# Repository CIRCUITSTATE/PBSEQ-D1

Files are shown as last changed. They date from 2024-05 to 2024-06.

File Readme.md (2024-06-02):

# PBSEQ-D1

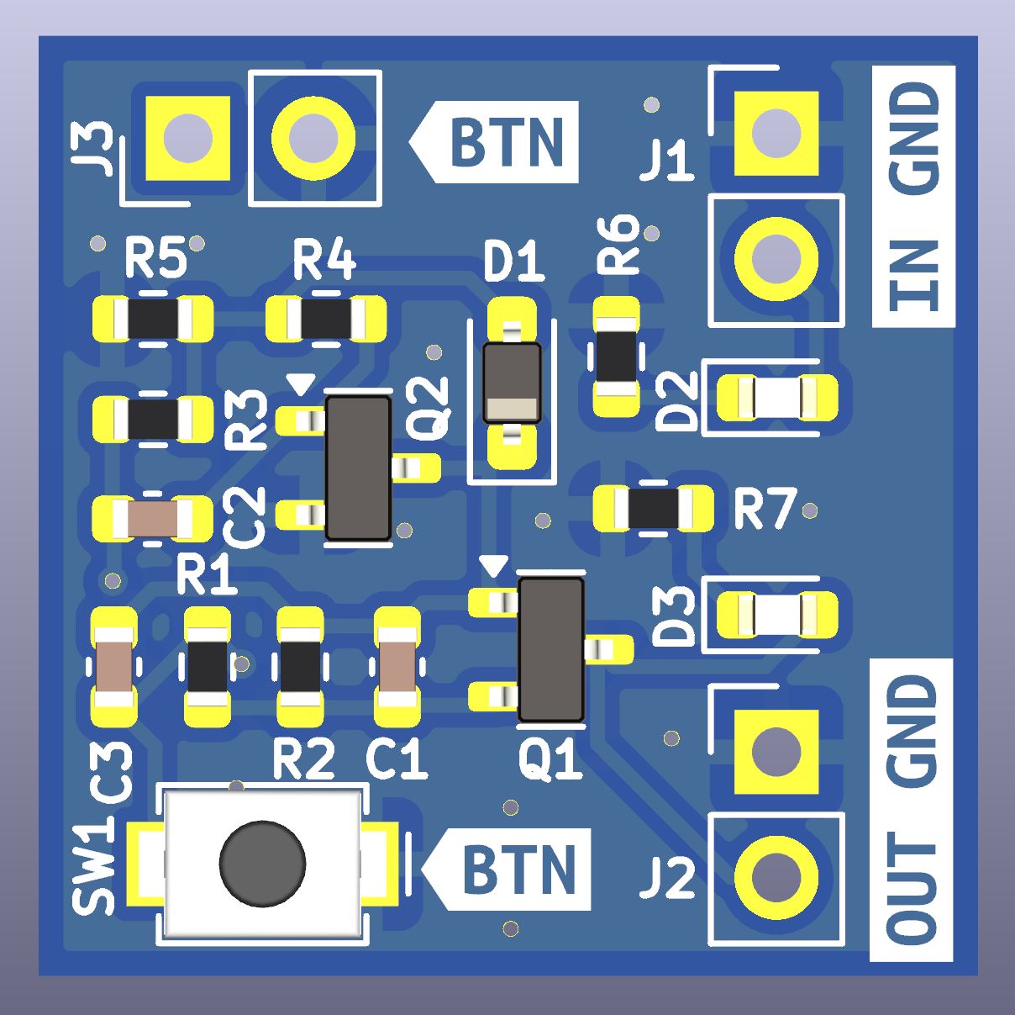
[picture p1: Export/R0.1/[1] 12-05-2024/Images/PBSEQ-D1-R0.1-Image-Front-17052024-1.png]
PBSEQ-D1 Front


**PBSEQ-D1** is a push-button based power sequencer demo board designed in KiCad. You can press the push-button momentarily to turn on the output. Pressing and and holding will turn off the output. A PMOS transistor is used as a high-side switch to control the power. An NMOS transistor controls the power sequencing. This demo project is fully open-source and you can find the source design files here.

A tutorial of designing and testing the circuit will soon be available at [CIRCUITSTATE](https://www.circuitstate.com/).

## Project Details

- **Parent Project:** PBSEQ
- **Variant Name:** PBSEQ-D1
- **Latest Revision:** `R0.2`
- **EDA Tools:** KiCad V8
- **Layer Count:** 2
- **Board Thickness:** 1.6 mm
- **Dimensions:** 19 x 19 mm

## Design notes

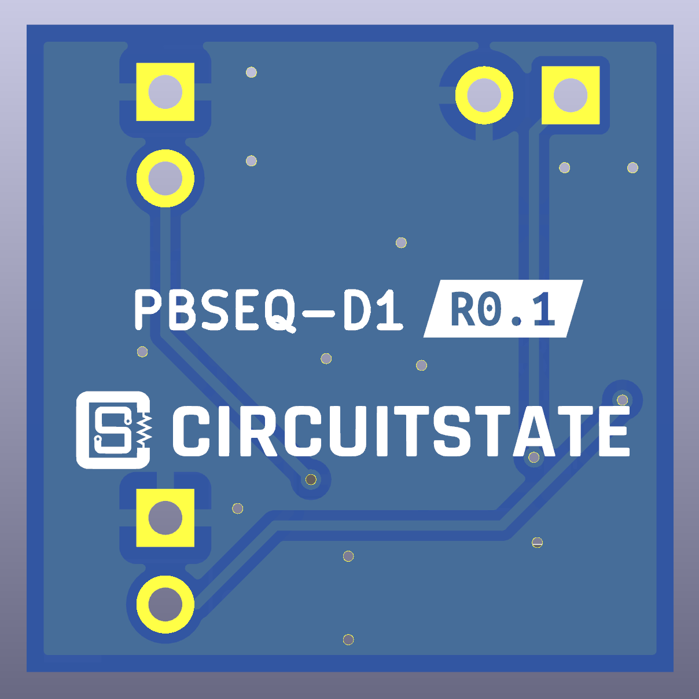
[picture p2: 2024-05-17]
Export/R0.1/[1] 12-05-2024/Images/PBSEQ-D1-R0.1-Image-Back-17052024-1.png

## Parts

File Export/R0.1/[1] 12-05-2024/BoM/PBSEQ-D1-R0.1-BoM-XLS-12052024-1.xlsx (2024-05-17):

# | Reference | Value | Name | Footprint | Qty | MPN | MFR | DNP
1 | C1 | 0.1uF |  | Capacitor_SMD:C_0603_1608Metric | 1 | 0603B104J500CT | Walsin
2 | C2 | 10uF |  | Capacitor_SMD:C_0603_1608Metric | 1 | 0603X106K100CT | Walsin
3 | C3 | 1uF |  | Capacitor_SMD:C_0603_1608Metric | 1 | CC0603KRX5R9BB105 | Yageo
4 | D1 | 1N4148 |  | Diode_SMD:D_SOD-323_HandSoldering | 1 | 1N4148WS | onsemi
5 | D2 | RED | INPUT | LED_SMD:LED_0603_1608Metric | 1 | 19-21SURC/S530-A2/TR8 | Everlight
6 | D3 | YELLOW | OUTPUT | LED_SMD:LED_0603_1608Metric | 1 | 19-213/Y2C-FN2P2VZ/3T | Everlight
7 | J1 | POWER IN | POWER IN | Connector_PinHeader_2.54mm:PinHeader_1x02_P2.54mm_Vertical | 1 | DNP
8 | J2 | POWER OUT | POWER OUT | Connector_PinHeader_2.54mm:PinHeader_1x02_P2.54mm_Vertical | 1 | DNP
9 | J3 | BUTTON | POWER IN | Connector_PinHeader_2.54mm:PinHeader_1x02_P2.54mm_Vertical | 1 | DNP
10 | Q1 | AO3401A |  | Package_TO_SOT_SMD:SOT-23 | 1 | AO3401A | Alpha & Omega
11 | Q2 | AO3400A |  | Package_TO_SOT_SMD:SOT-23 | 1 | AO3400A | Alpha & Omega
12 | R1 | 10K |  | Resistor_SMD:R_0603_1608Metric | 1 | WR06X1002FTL | Walsin
13 | R4 | 300K |  | Resistor_SMD:R_0603_1608Metric | 1 | WR06X3003FTL | Walsin
14 | R5 | 1M |  | Resistor_SMD:R_0603_1608Metric | 1 | WR06X1004FTL | Walsin
15 | R6 | 1K |  | Resistor_SMD:R_0603_1608Metric | 1 | WR06X1001FTL | Walsin
16 | R7 | 200R |  | Resistor_SMD:R_0603_1608Metric | 1 | WR06X2000FTL | Walsin
17 | R2,R3 | 100K |  | Resistor_SMD:R_0603_1608Metric | 2 | WR06X1003FTL | Walsin
18 | SW1 | BUTTON | BUTTON | CIRCUITSTATE_Switch_SMD:CK_SW_SPST_UK-B0273-SP25Y | 1 | TS-1088R-02526 | XUNPU

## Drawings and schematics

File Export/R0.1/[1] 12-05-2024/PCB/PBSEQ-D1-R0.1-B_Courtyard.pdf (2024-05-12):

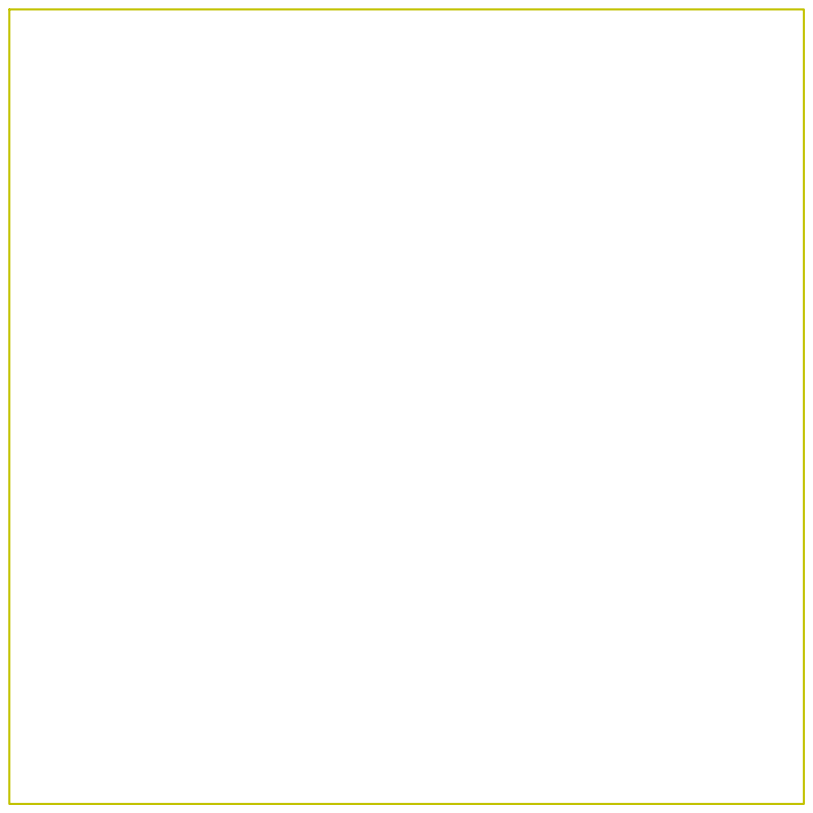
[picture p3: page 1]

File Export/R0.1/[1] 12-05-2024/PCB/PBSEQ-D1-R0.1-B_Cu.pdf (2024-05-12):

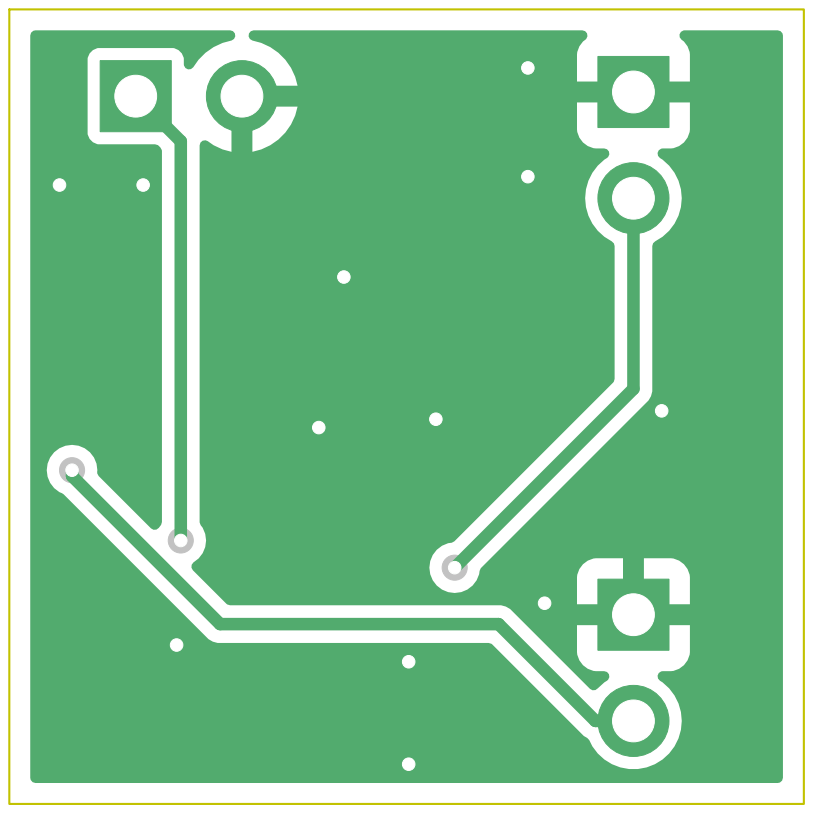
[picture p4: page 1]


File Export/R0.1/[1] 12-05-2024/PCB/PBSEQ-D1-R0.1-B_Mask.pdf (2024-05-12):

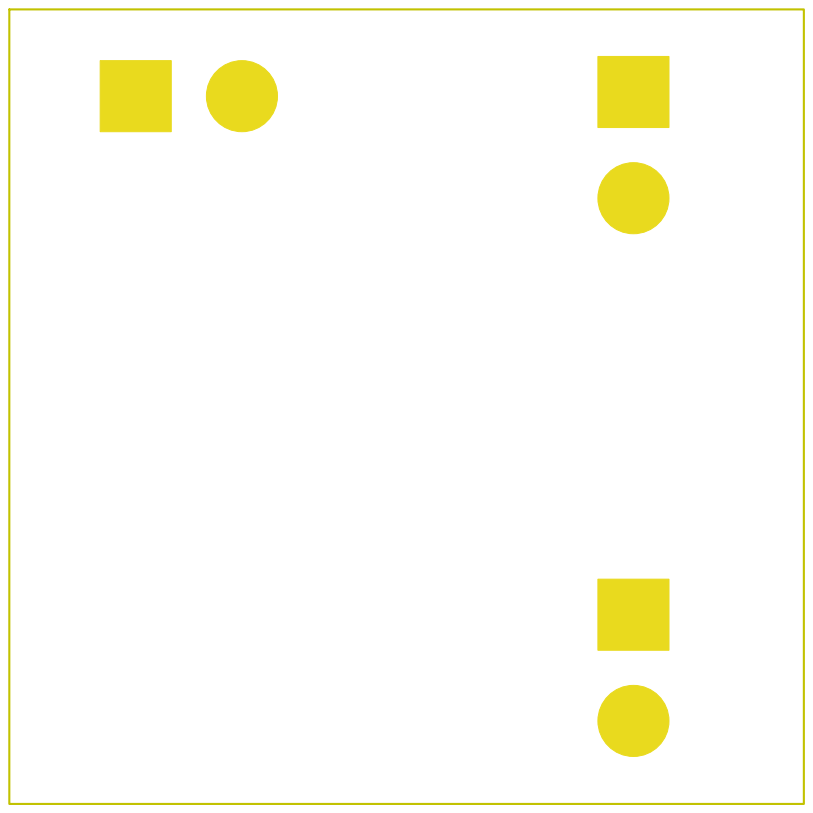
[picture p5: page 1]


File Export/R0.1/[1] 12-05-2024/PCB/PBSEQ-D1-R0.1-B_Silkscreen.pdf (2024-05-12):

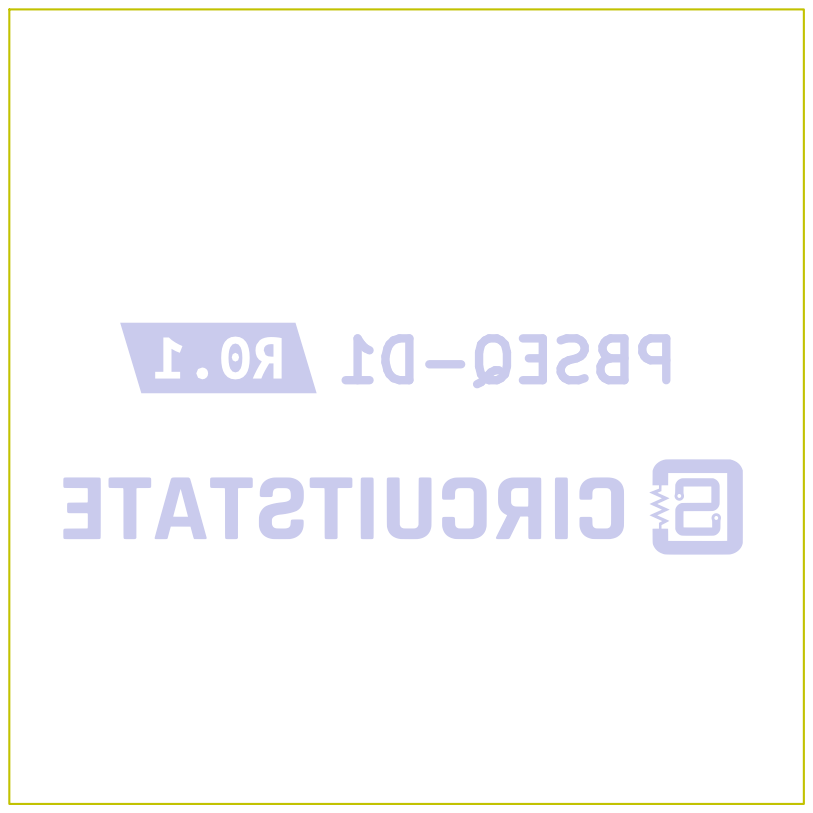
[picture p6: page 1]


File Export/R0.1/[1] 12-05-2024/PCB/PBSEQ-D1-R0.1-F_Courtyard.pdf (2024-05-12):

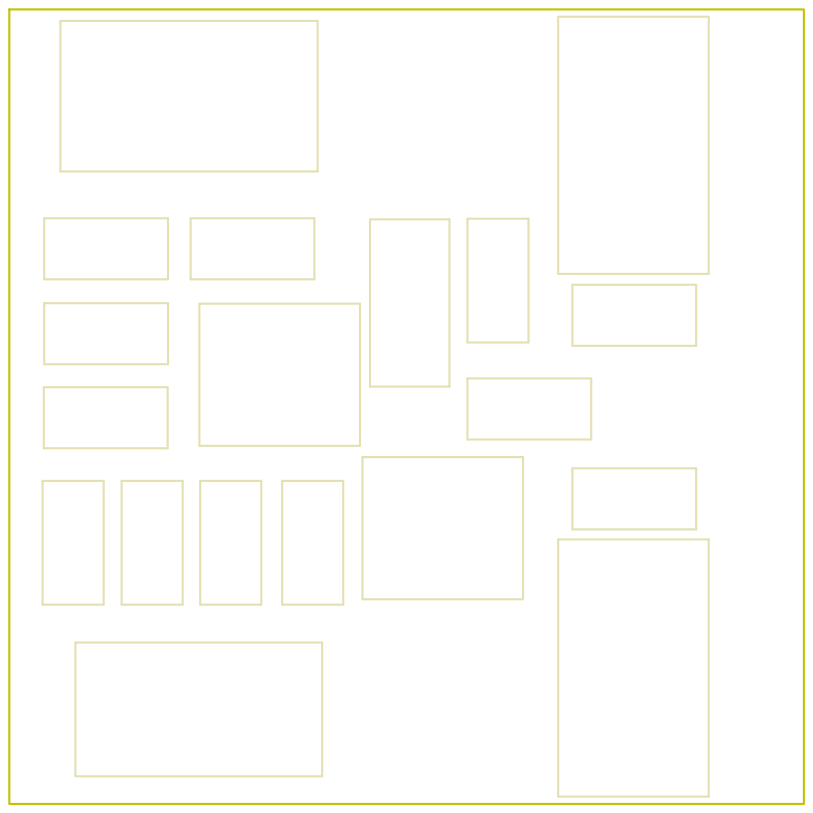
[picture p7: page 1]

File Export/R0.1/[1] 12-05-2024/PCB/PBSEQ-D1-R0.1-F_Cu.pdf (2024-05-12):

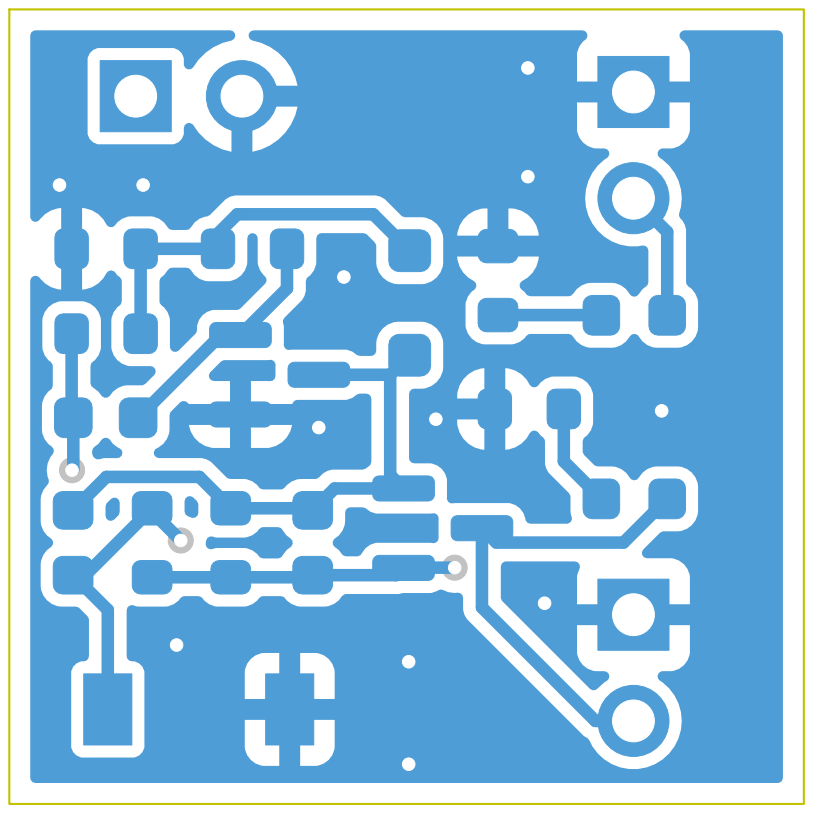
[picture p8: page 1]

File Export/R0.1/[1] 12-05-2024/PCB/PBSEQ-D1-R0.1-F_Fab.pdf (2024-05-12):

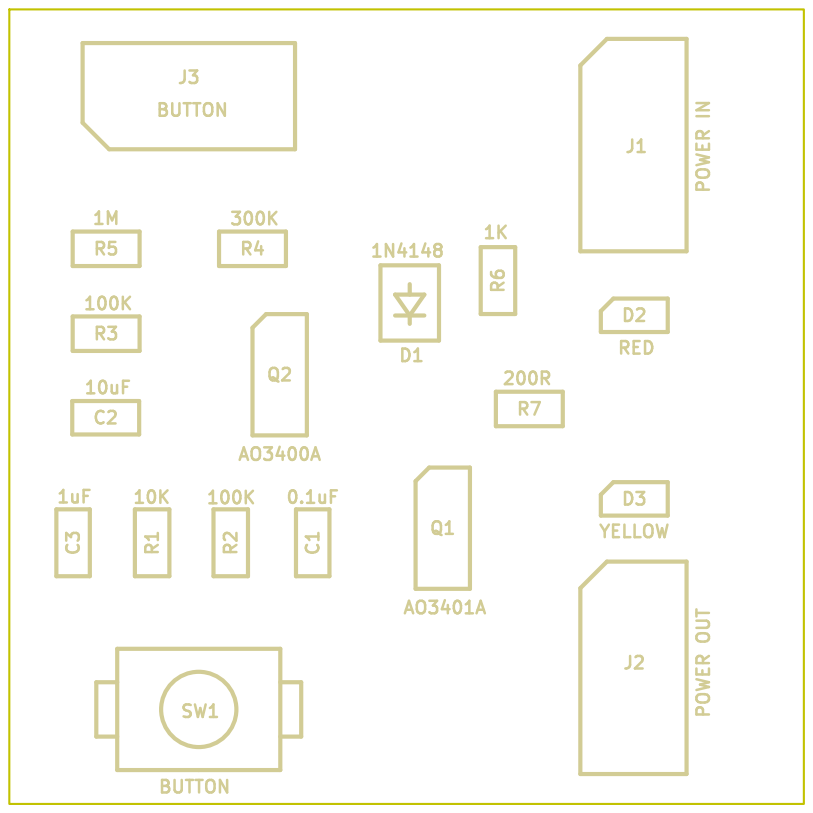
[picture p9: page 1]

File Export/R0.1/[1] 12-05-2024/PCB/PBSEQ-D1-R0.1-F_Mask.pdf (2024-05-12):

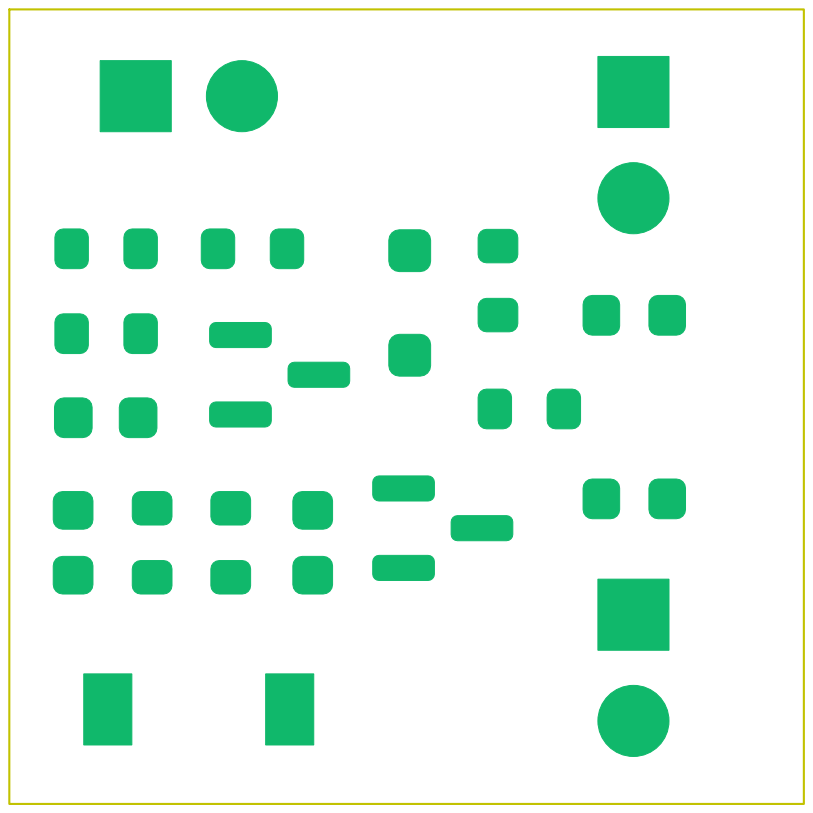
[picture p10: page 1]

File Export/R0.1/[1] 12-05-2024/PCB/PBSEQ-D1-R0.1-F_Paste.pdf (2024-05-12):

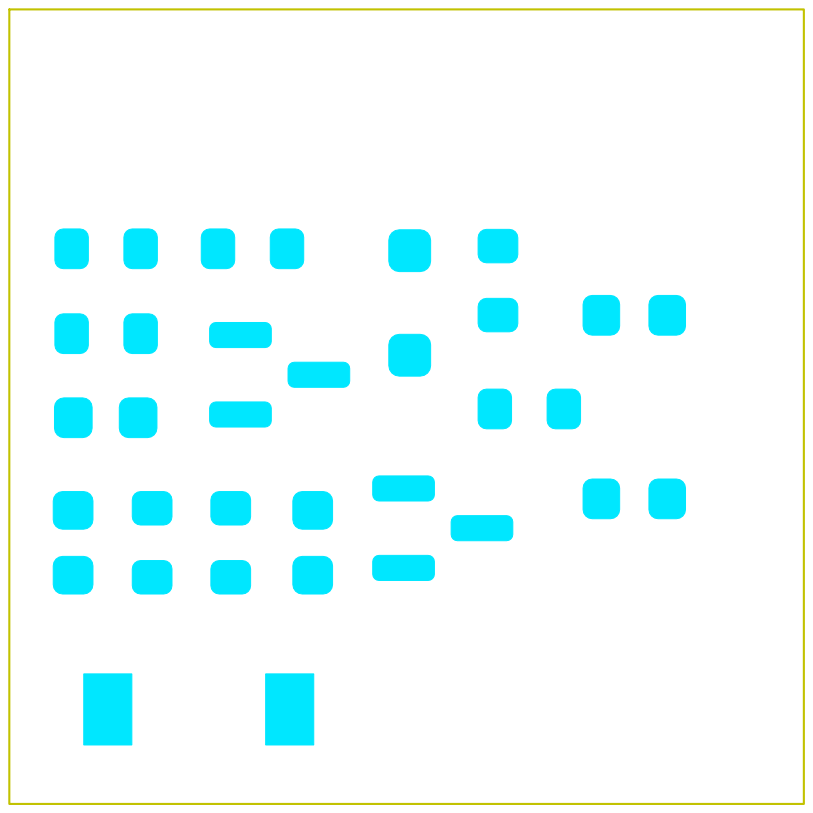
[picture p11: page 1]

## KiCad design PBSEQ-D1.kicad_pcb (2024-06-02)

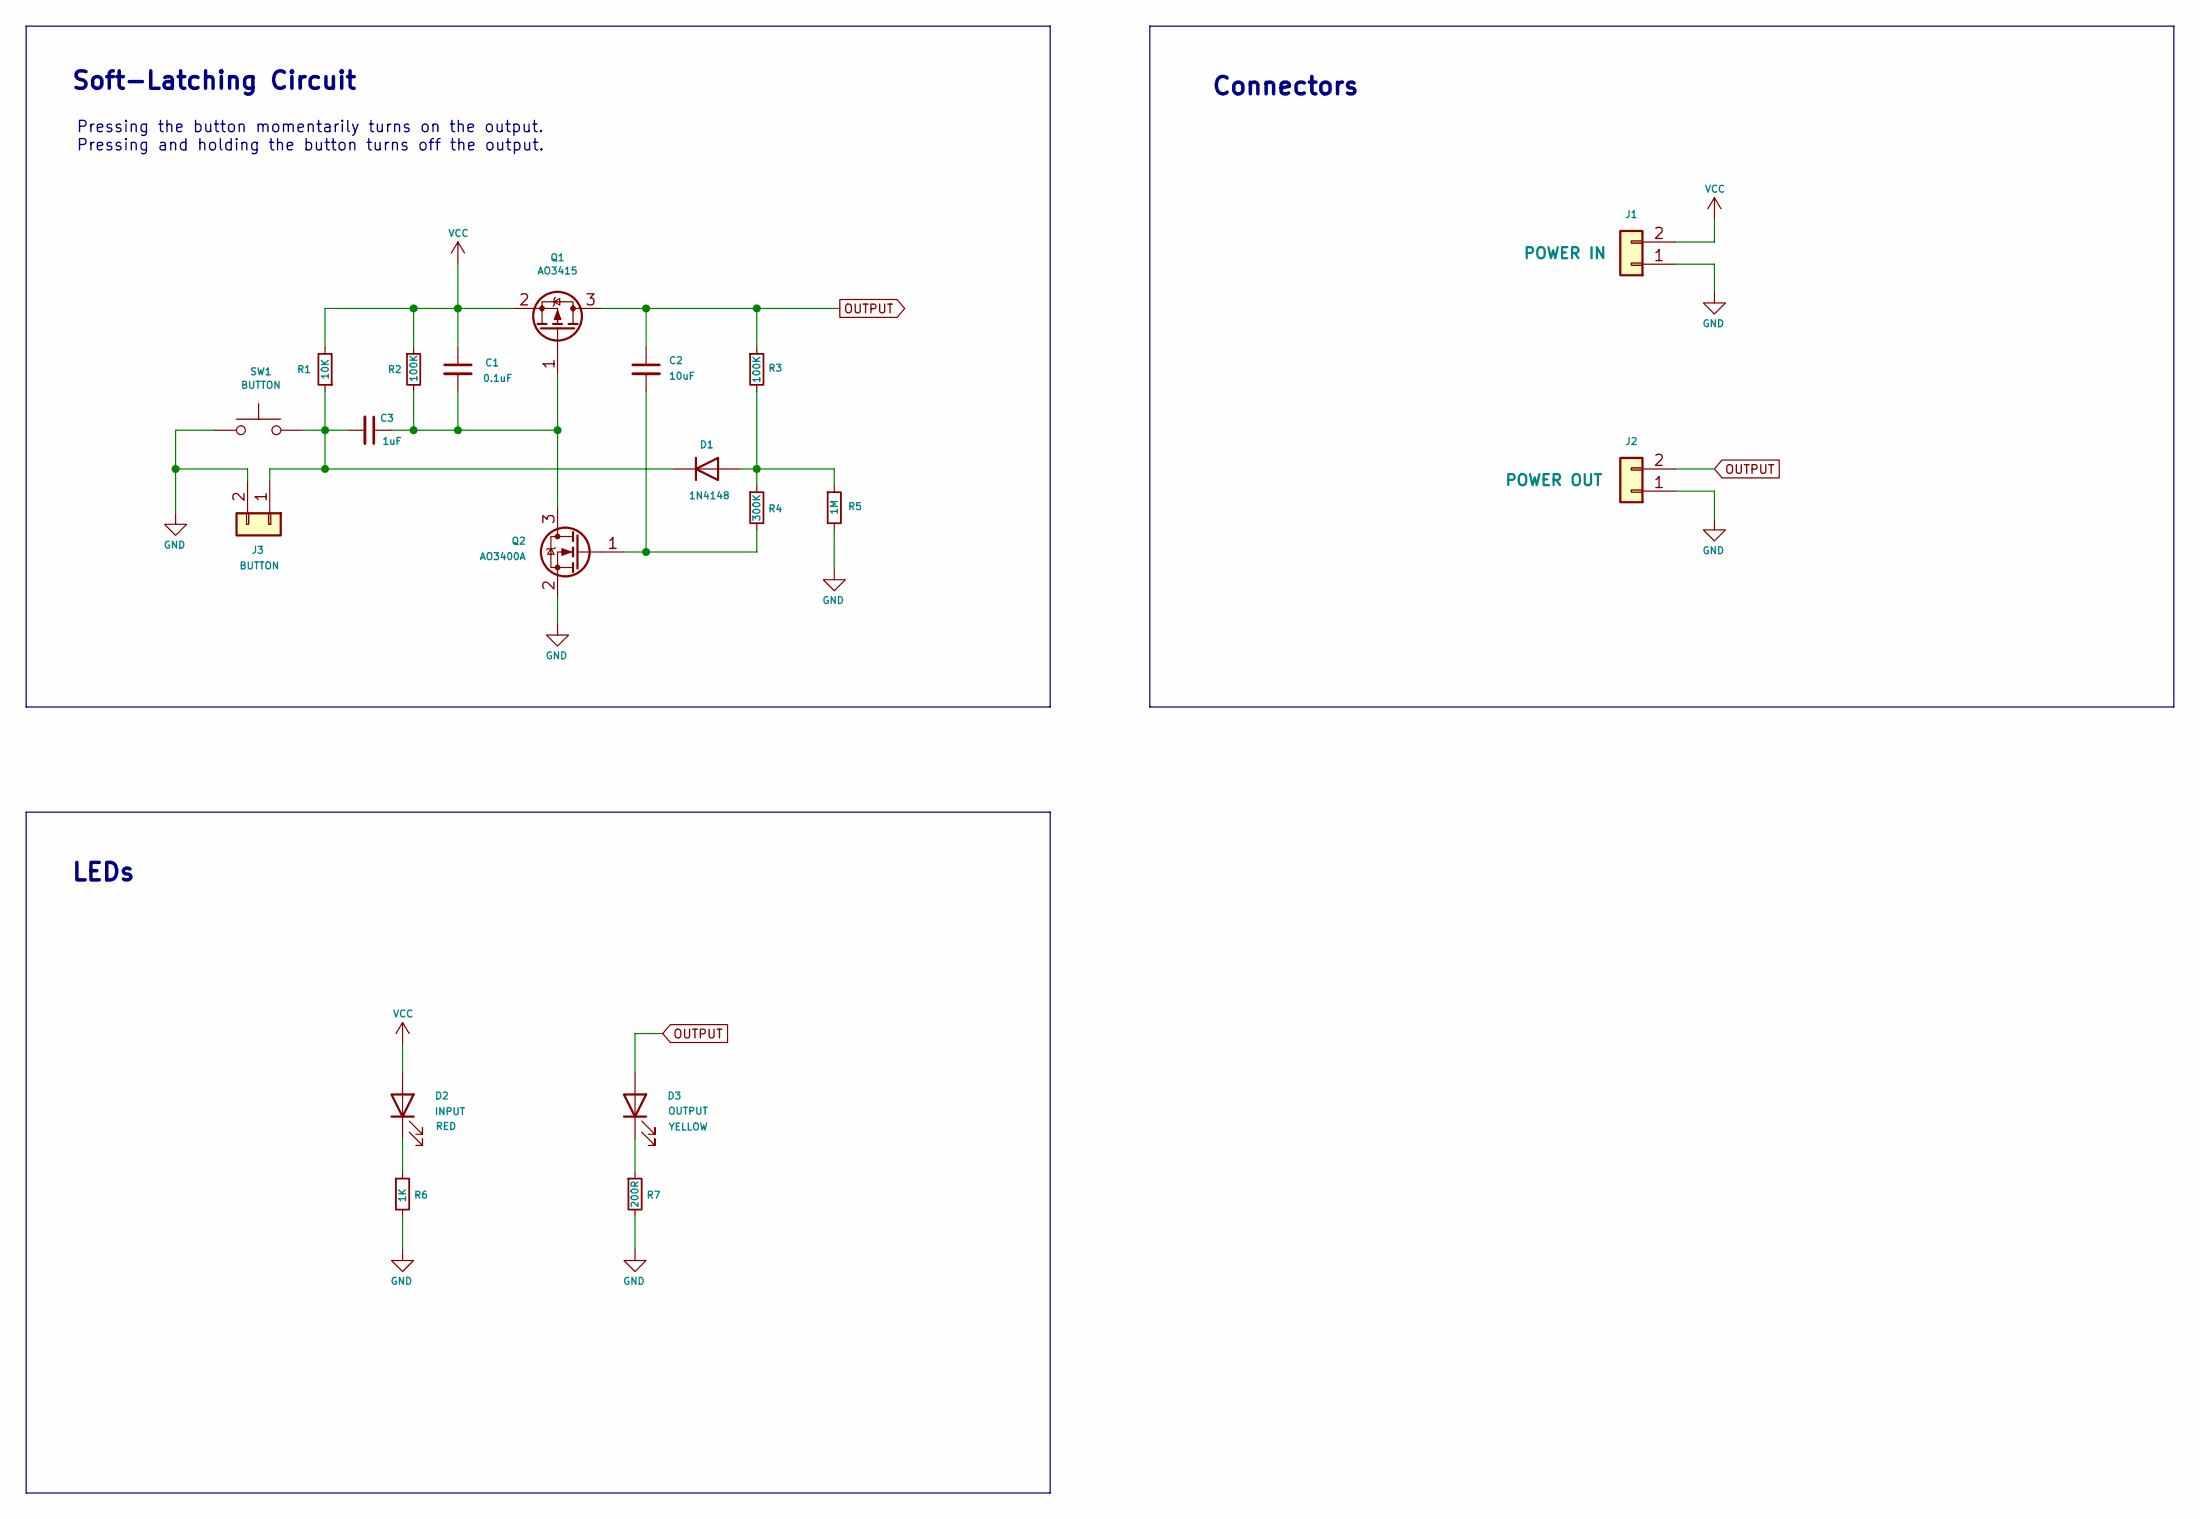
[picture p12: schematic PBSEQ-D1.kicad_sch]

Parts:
C1: 0.1uF; C_0603_1608Metric_Pad1.08x0.95mm_HandSolder; MPN 0603B104J500CT
C2: 10uF; C_0603_1608Metric_Pad1.08x0.95mm_HandSolder; MPN 0603X106K100CT
C3: 1uF; C_0603_1608Metric_Pad1.08x0.95mm_HandSolder; MPN CC0603KRX5R9BB105
D1: 1N4148; D_SOD-323_HandSoldering; MPN 1N4148WS
D2: RED; LED_0603_1608Metric_Pad1.05x0.95mm_HandSolder; MPN 19-21SURC/S530-A2/TR8
D3: YELLOW; LED_0603_1608Metric_Pad1.05x0.95mm_HandSolder; MPN 19-213/Y2C-FN2P2VZ/3T
J1: POWER IN; PinHeader_1x02_P2.54mm_Vertical; MPN DNP
J2: POWER OUT; PinHeader_1x02_P2.54mm_Vertical; MPN DNP
J3: BUTTON; PinHeader_1x02_P2.54mm_Vertical; MPN DNP
Q1: AO3415; SOT-23; MPN AO3415
Q2: AO3400A; SOT-23; MPN AO3400A
R1: 10K; R_0603_1608Metric_Pad0.98x0.95mm_HandSolder; MPN WR06X1002FTL
R2, R3: 100K; R_0603_1608Metric_Pad0.98x0.95mm_HandSolder; MPN WR06X1003FTL
R4: 300K; R_0603_1608Metric_Pad0.98x0.95mm_HandSolder; MPN WR06X3003FTL
R5: 1M; R_0603_1608Metric_Pad0.98x0.95mm_HandSolder; MPN WR06X1004FTL
R6: 1K; R_0603_1608Metric_Pad0.98x0.95mm_HandSolder; MPN WR06X1001FTL
R7: 200R; R_0603_1608Metric_Pad0.98x0.95mm_HandSolder; MPN WR06X2000FTL
SW1: BUTTON; CK_SW_SPST_UK-B0273-SP25Y; MPN TS-1088R-02526

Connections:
GND: J1.1, J2.1, J3.2, Q2.2 (S), R5.2, R6.2, R7.2, SW1.1
unnamed: D1.2 (A), R3.2, R4.1, R5.1
unnamed: C3.2, D1.1 (K), J3.1, R1.1, SW1.2
unnamed: D2.1 (K), R6.1
unnamed: D3.1 (K), R7.1
unnamed: C1.2, C3.1, Q1.1 (G), Q2.3 (D), R2.2
unnamed: C2.2, Q2.1 (G), R4.2
OUTPUT: C2.1, D3.2 (A), J2.2, Q1.3 (D), R3.1
VCC: C1.1, D2.2 (A), J1.2, Q1.2 (S), R1.2, R2.1

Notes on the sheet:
Connectors
LEDs
Pressing the button momentarily turns on the output. Pressing and holding the button turns off the output.
Soft-Latching Circuit

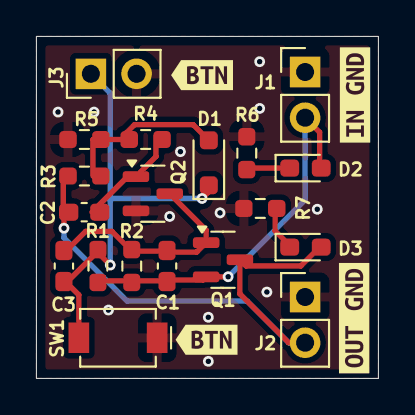
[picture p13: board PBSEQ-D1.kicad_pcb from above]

Board: 2 copper layers, 19.0 x 19.0 mm, 24 parts (1 on the bottom side), 9 nets.

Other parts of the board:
kibuzzard-663FBC0C, kibuzzard-663FBC0C#2: G***; kibuzzard-663FBC0C
kibuzzard-663FBCF2: G***; kibuzzard-663FBCF2
kibuzzard-663FBD0F: G***; kibuzzard-663FBD0F
kibuzzard-665C27BB: G***; kibuzzard-665C27BB

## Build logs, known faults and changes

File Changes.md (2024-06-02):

#
### **+05:30 01:47:26 PM 02-06-2024, Sunday**

  * Fixed the diode connection issue. The Cathode was connected to the wrong point.
  * Updated `Q1` to AO3415.
  * The circuit has been tested and working.
  * Updated all 0603 footprints to hand-soldering type for easy soldering.
  * Rearranged the silkscreen labels.
  * DRC passes.
  * Updated BoM.
  * New Revision`R0.2`.

#
### **+05:30 10:37:34 PM 17-05-2024, Friday**

  * Exported images of the PCB.
  * Added XLS BoM.
  * Updated Readme.

#
### **+05:30 04:22:24 PM 12-05-2024, Sunday**

  * Added gitignore.

#
### **+05:30 04:21:18 PM 12-05-2024, Sunday**

  * Updated Readme.

#
### **+05:30 04:07:39 PM 12-05-2024, Sunday**

  * Completed PCB routing.
  * DRC passes.
  * Exported manufacturing files.
  * Added Changes and Readme.
  * New Revision `R0.1`.

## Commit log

2024-05-12 R0.1 Init Commit
    * Completed PCB routing.
    * DRC passes.
    * Exported manufacturing files.
    * New Revision `R0.1`.
    [PBSEQ-D1-R0.1-BoM-CSV-12052024-1.csv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]
2024-05-17 Exported images of the PCB
    * Added XLS BoM.
    * Updated Readme.
    [PBSEQ-D1-R0.1-BoM-XLS-12052024-1.xlsx]
2024-06-02 R0.2
    * Fixed the diode connection issue. The Cathode was connected to the wrong point.
    * Updated `Q1` to AO3415.
    * The circuit has been tested and working.
    * Updated all 0603 footprints to hand-soldering type for easy soldering.
    * Rearranged the silkscreen labels.
    * Updated BoM.
    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
    [PBSEQ-D1.kicad_pcb, PBSEQ-D1.kicad_sch]
